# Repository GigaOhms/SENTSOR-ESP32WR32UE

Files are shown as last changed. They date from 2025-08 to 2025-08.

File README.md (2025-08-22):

# Learn KiCad Through a ESP32-micro Compact PCB Design Project

This repository is a learning resource to explore **PCB design with KiCad** through a practical project: a compact and powerful ESP32-based board.  
The reference for this project comes from [Sentsor Core ESP32-Micro](https://oshwlab.com/sentsor-project/sentsor-core-esp32-micro).

---

## Project Image

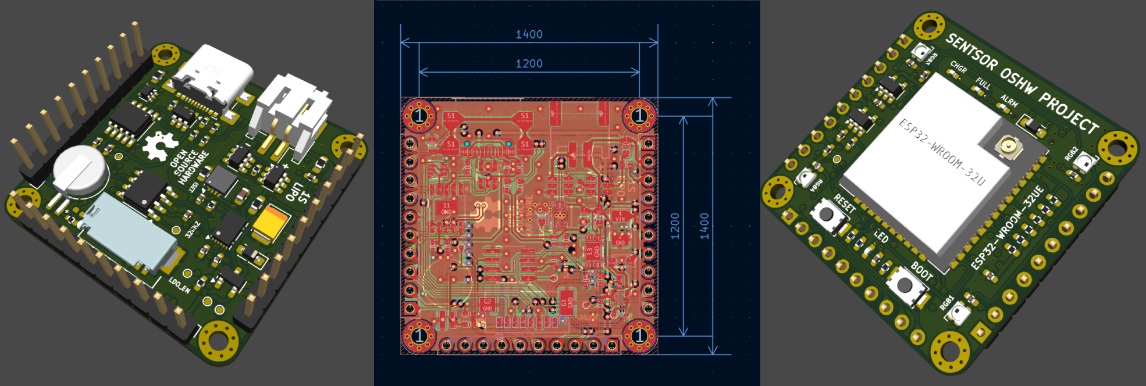
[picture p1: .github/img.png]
Project Preview


---

## Description

- **Super compact & powerful**, measured only 35.56x35.56mm (1400x1400mil) with 3x10P standard pitch 2.54mm (100mil) pinout, packing all the onboard features.  
- **ESP32-WROOM-32UE**, comes with latest ECO V3 Dual Core 32-bit LX6 microprocessor with clock up to 240MHz, ULP co-processor, 520kB SRAM, 16MB flash.  
- **802.11b/g/n WiFi Connectivity**, support mode STA/AP/STA+AP mode with external antenna using U.FL/IPEX connector allowing the board to be installed inside the enclosure without worrying transceiver signal quality.  
- **Bluetooth 4.2 Connectivity**, support classic bluetooth and Low Energy (LE) protocol.  
- **CP2104 UART to USB Bridge**, full-speed programmer & data port with auto-reset trigger using DTR and RTS line.  
- **DS3231M RTC**, extremely accurate ±5ppm RTC with alarm trigger capability and onboard MS621FE rechargeable backup battery. Connected via I2C at address 0x68.  
- **Battery Powered**, run SENTSOR board everywhere without power supply issue with 1-cell Lithium Ion/Polymer battery via JST-PH connector.  
- **CN3165 Battery Charger**, solar-powered and USB-compatible Lithium Ion/Polymer charger with on-chip adaptive charging current for wide range of input power scenario.  
- **DW01A Battery Protection**, battery usage protection against over-charge, over-discharge, over-current, and short circuit.  
- **BQ27441-G1 Battery Fuel Gauge**, accurately monitor your battery Relative State of Charge (RSOC).  
- **RT9078 & RT9013 LDO**, dual low quiescent current LDO design providing configurable +3.3V power rail up to 800mA.  
- **Super Low Power**, measured sleep mode power consumption down to XuW (XuA XV at VBAT pin, LDO2 off).  
- **Built-in LED/RGB**, single color active-low LED connected to pin IO2, and 4xSK6812 addressable RGB LED connected to pin IO4. SK6812 data out is exposed so you can chain it up with the rest of the LED circuit.  
- **MicroSD socket**, connected via SPI with slave select (SS) at pin IO5.  
- **22 pin GPIO** @3V3 level, 3xUART, 2xSPI, 2xI2C, 2xI2S, 12bit ADC, 8bit DAC, hall-effect sensing, capacitive sensing, JTAG debug, etc.  
  Please see pinout poster/schematic file for more information.  

---

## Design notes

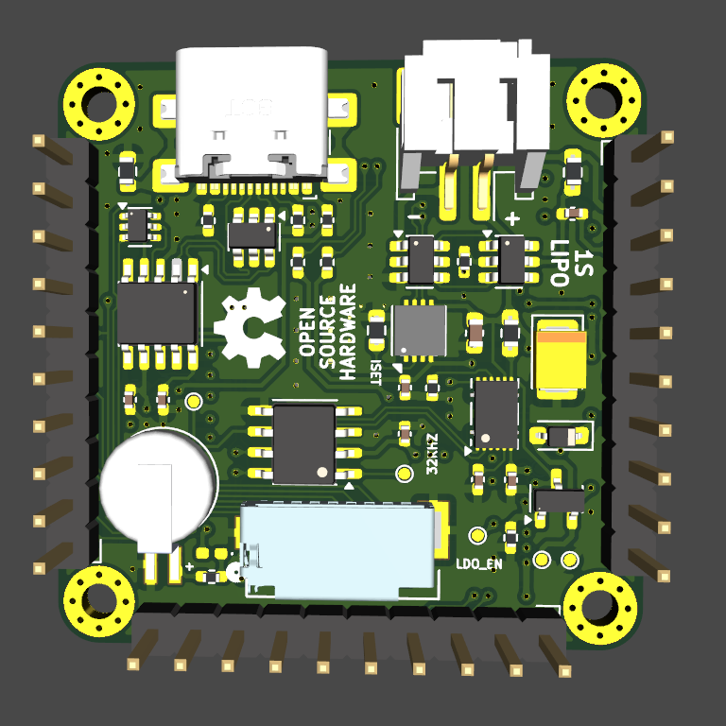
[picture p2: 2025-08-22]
.github/{3042503B-B515-44FC-A599-0AF2ED1924E2}.png

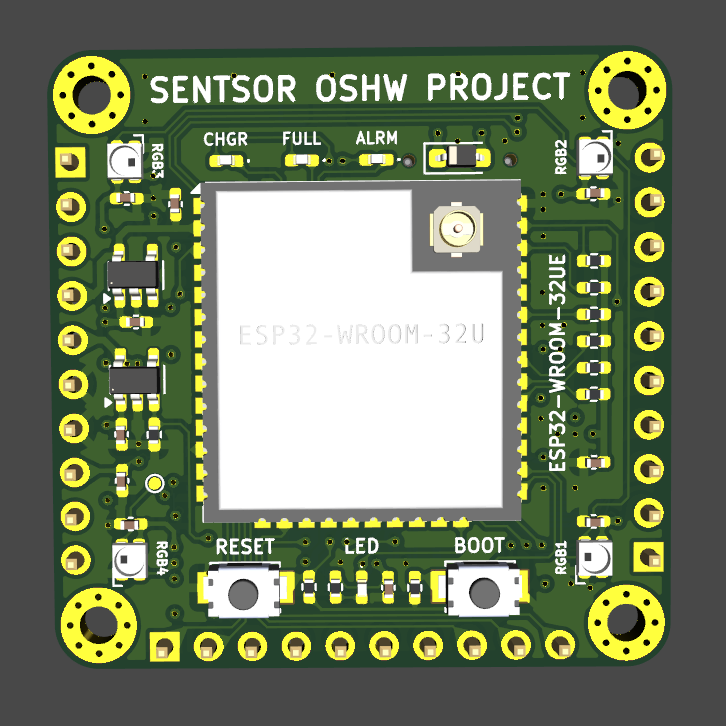
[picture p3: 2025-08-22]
.github/{C277C686-3AE4-48C9-9130-4F181D2F0E78}.png

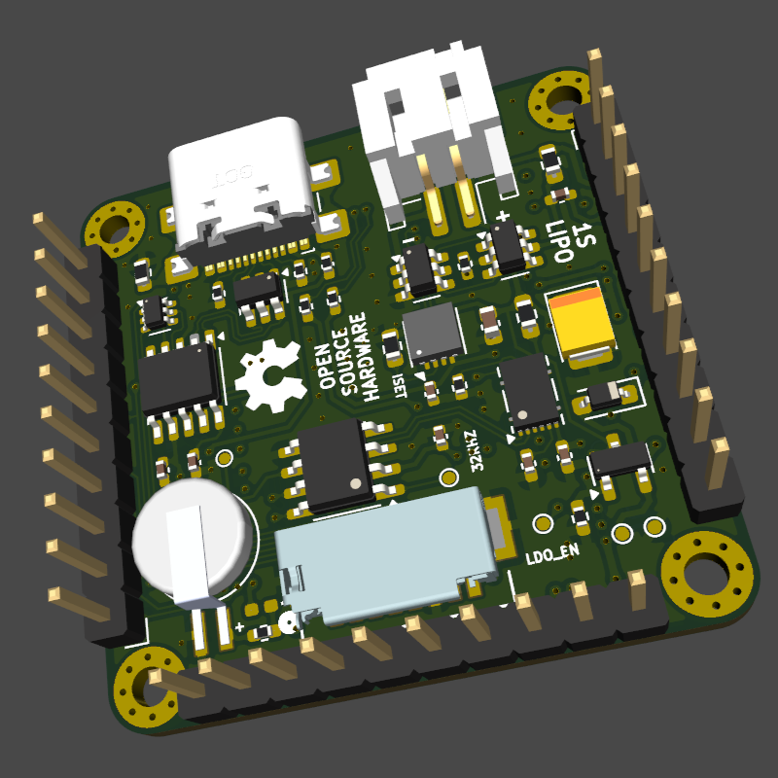
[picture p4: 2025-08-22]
.github/{8042447E-E397-4C2C-84E7-ECF5C29D7B32}.png

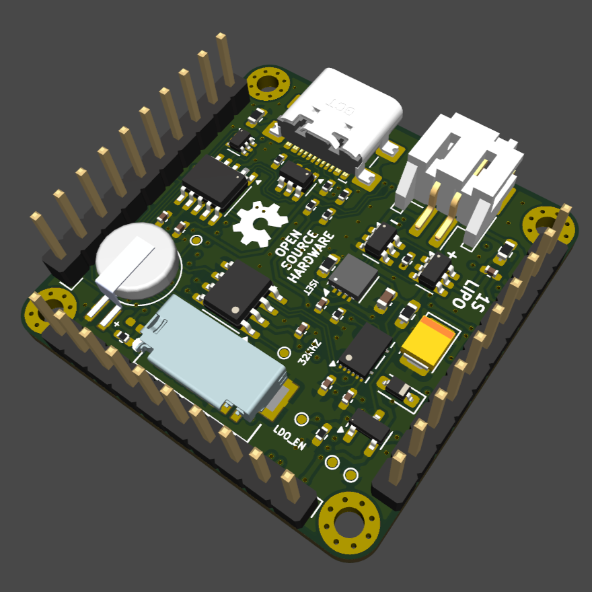
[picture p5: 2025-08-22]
.github/{378869CB-FA2F-42F7-B0C2-98885EA41B93}.png

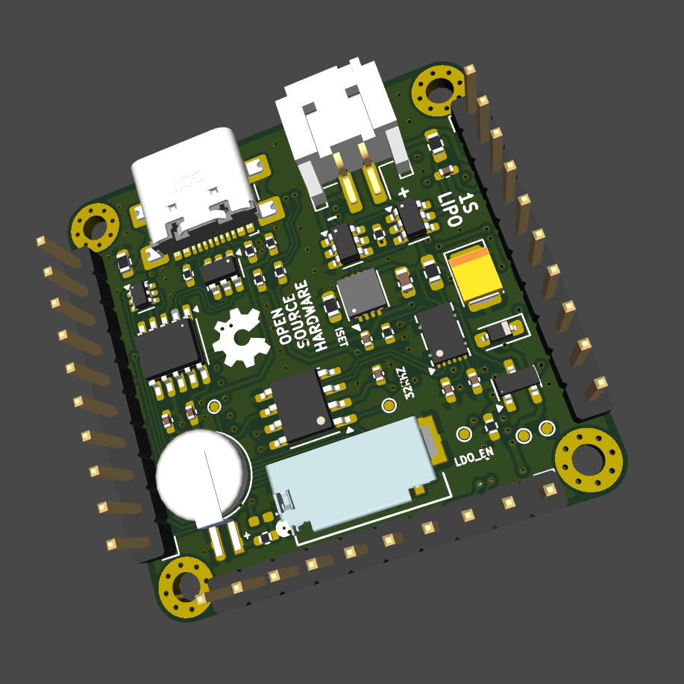
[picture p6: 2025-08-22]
.github/{2D30E0E1-55B5-4085-9390-B09677AA93EF}.png

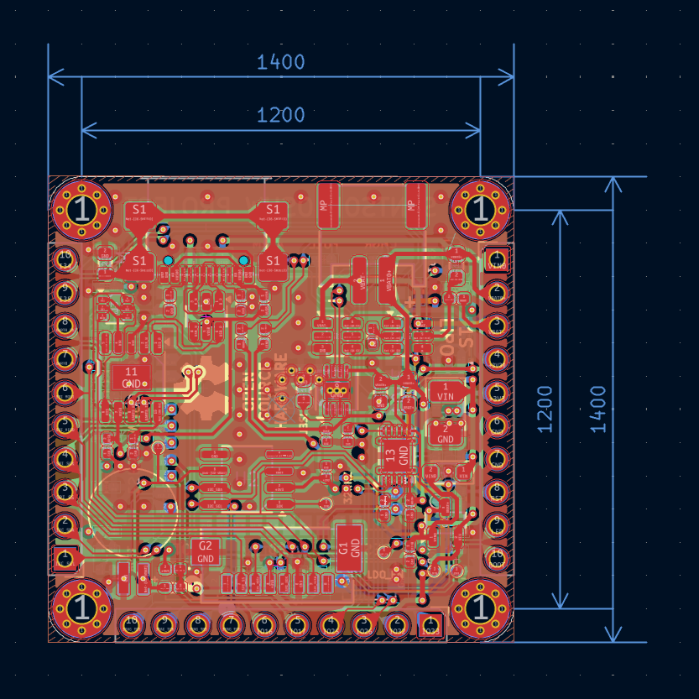
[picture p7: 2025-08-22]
.github/{8911B826-A0C5-4DD1-86A1-A8F6CBF12ACC}.png

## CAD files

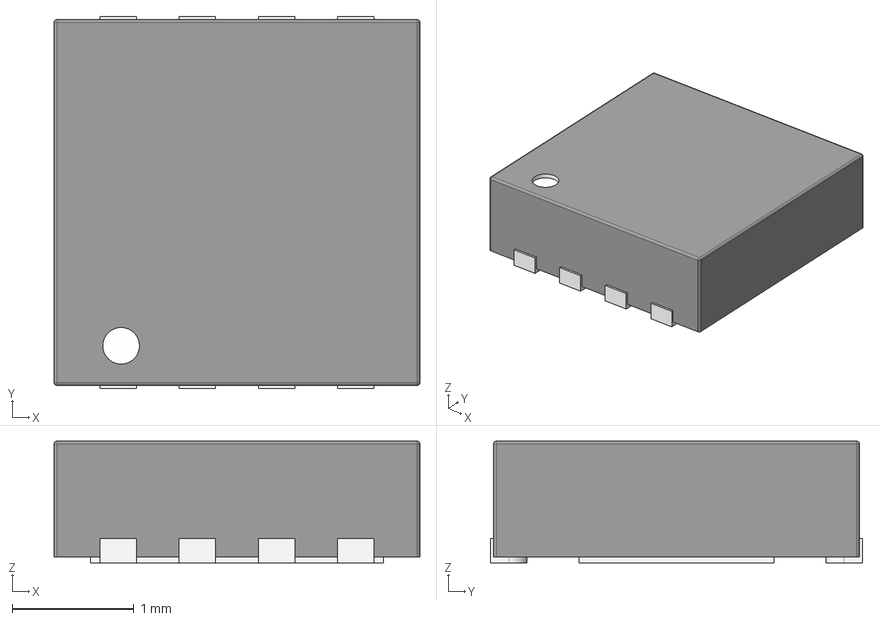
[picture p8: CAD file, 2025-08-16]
3dmodel/DFN-8 3x3.step
3.00 x 3.05 x 1.00 mm

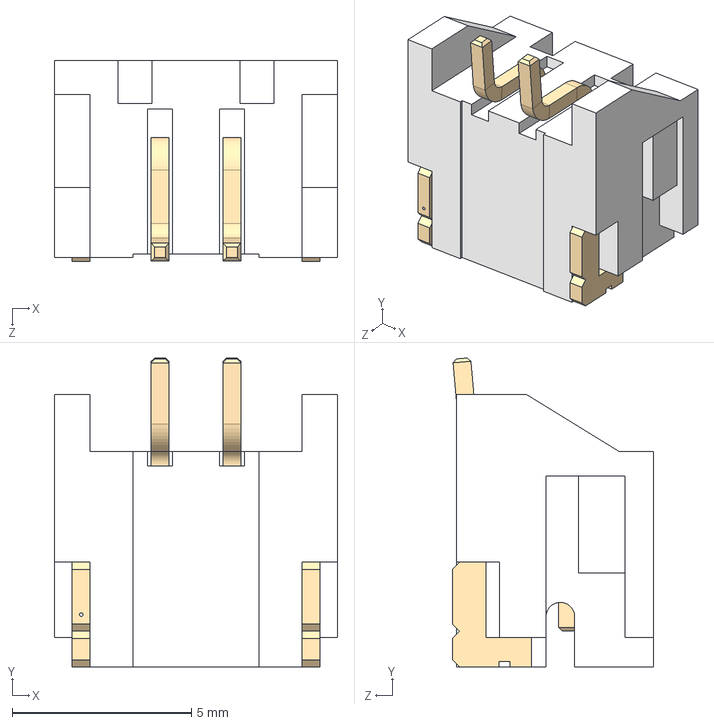
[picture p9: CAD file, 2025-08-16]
3dmodel/JST-S2B-PH-SM4-TB.STEP
7.90 x 8.61 x 5.61 mm

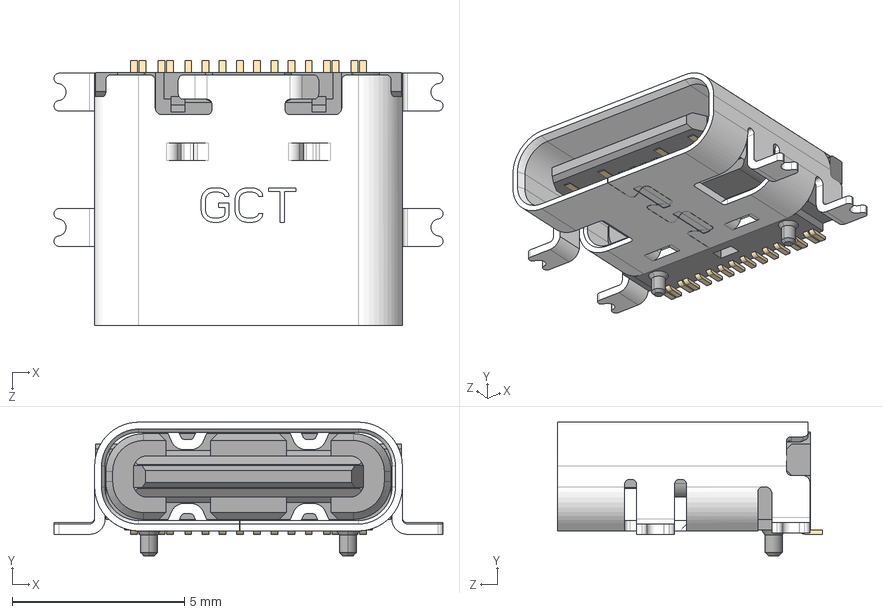
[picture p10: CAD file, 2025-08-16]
3dmodel/USB4110GFA--3DModel-STEP-269445.STEP
11.3 x 3.89 x 7.70 mm

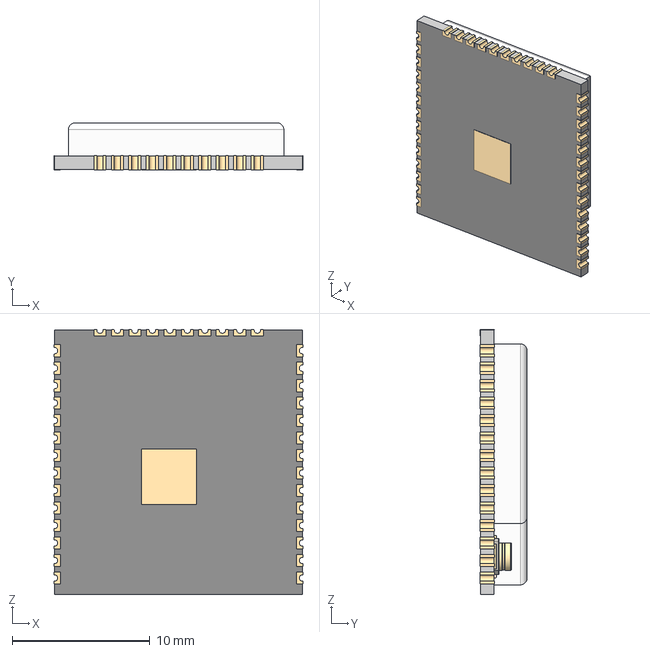
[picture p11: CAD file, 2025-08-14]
3dmodel/ESp32-WROOM-32U v3.step
18.1 x 3.44 x 19.2 mm

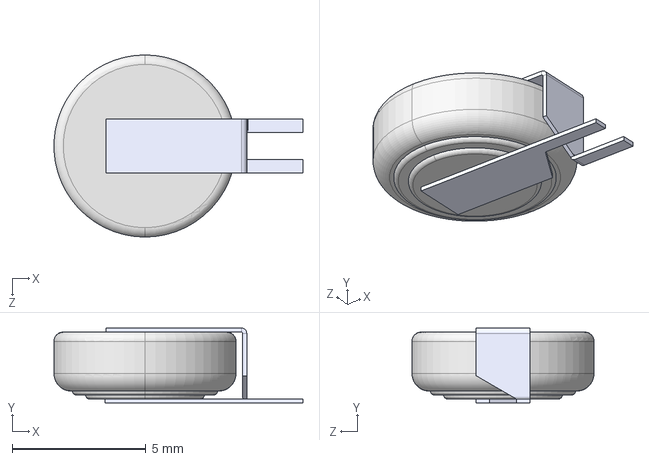
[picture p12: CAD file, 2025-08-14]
3dmodel/MS621FE.step
9.30 x 2.80 x 6.80 mm

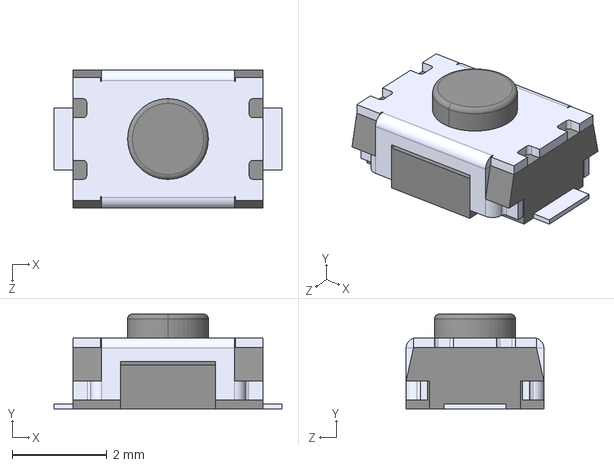
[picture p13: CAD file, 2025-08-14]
3dmodel/TS-1088-AR02016.step
4.80 x 2.00 x 2.90 mm

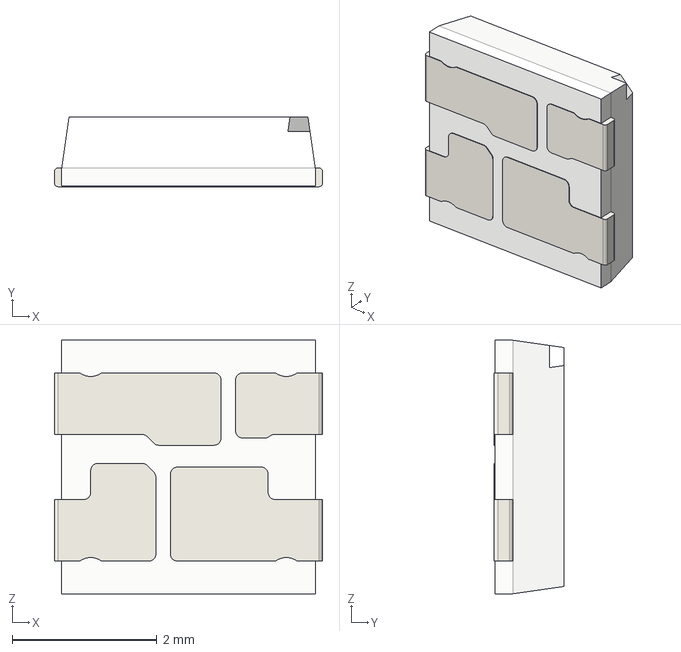
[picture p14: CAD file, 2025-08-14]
3dmodel/SMD SK6812 Super LED.step
3.70 x 0.96 x 3.50 mm

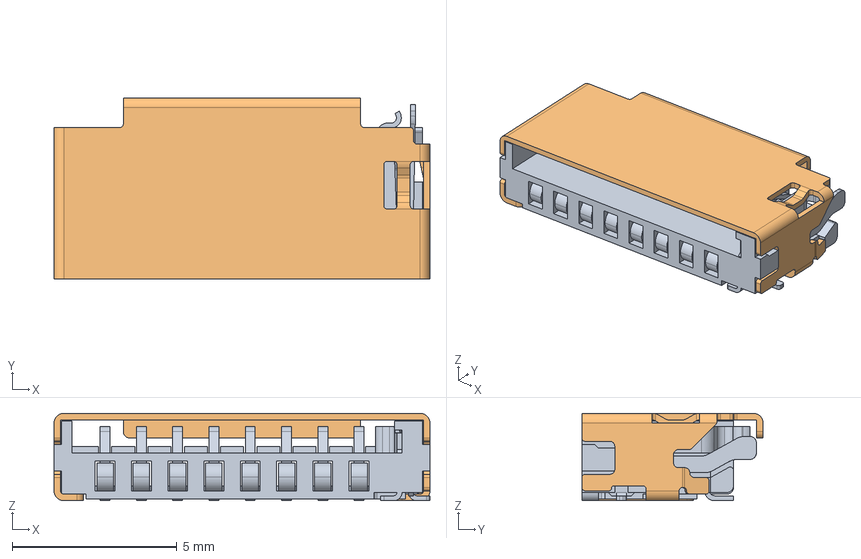
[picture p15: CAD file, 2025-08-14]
3dmodel/0473092651.stp
11.4 x 5.50 x 2.65 mm

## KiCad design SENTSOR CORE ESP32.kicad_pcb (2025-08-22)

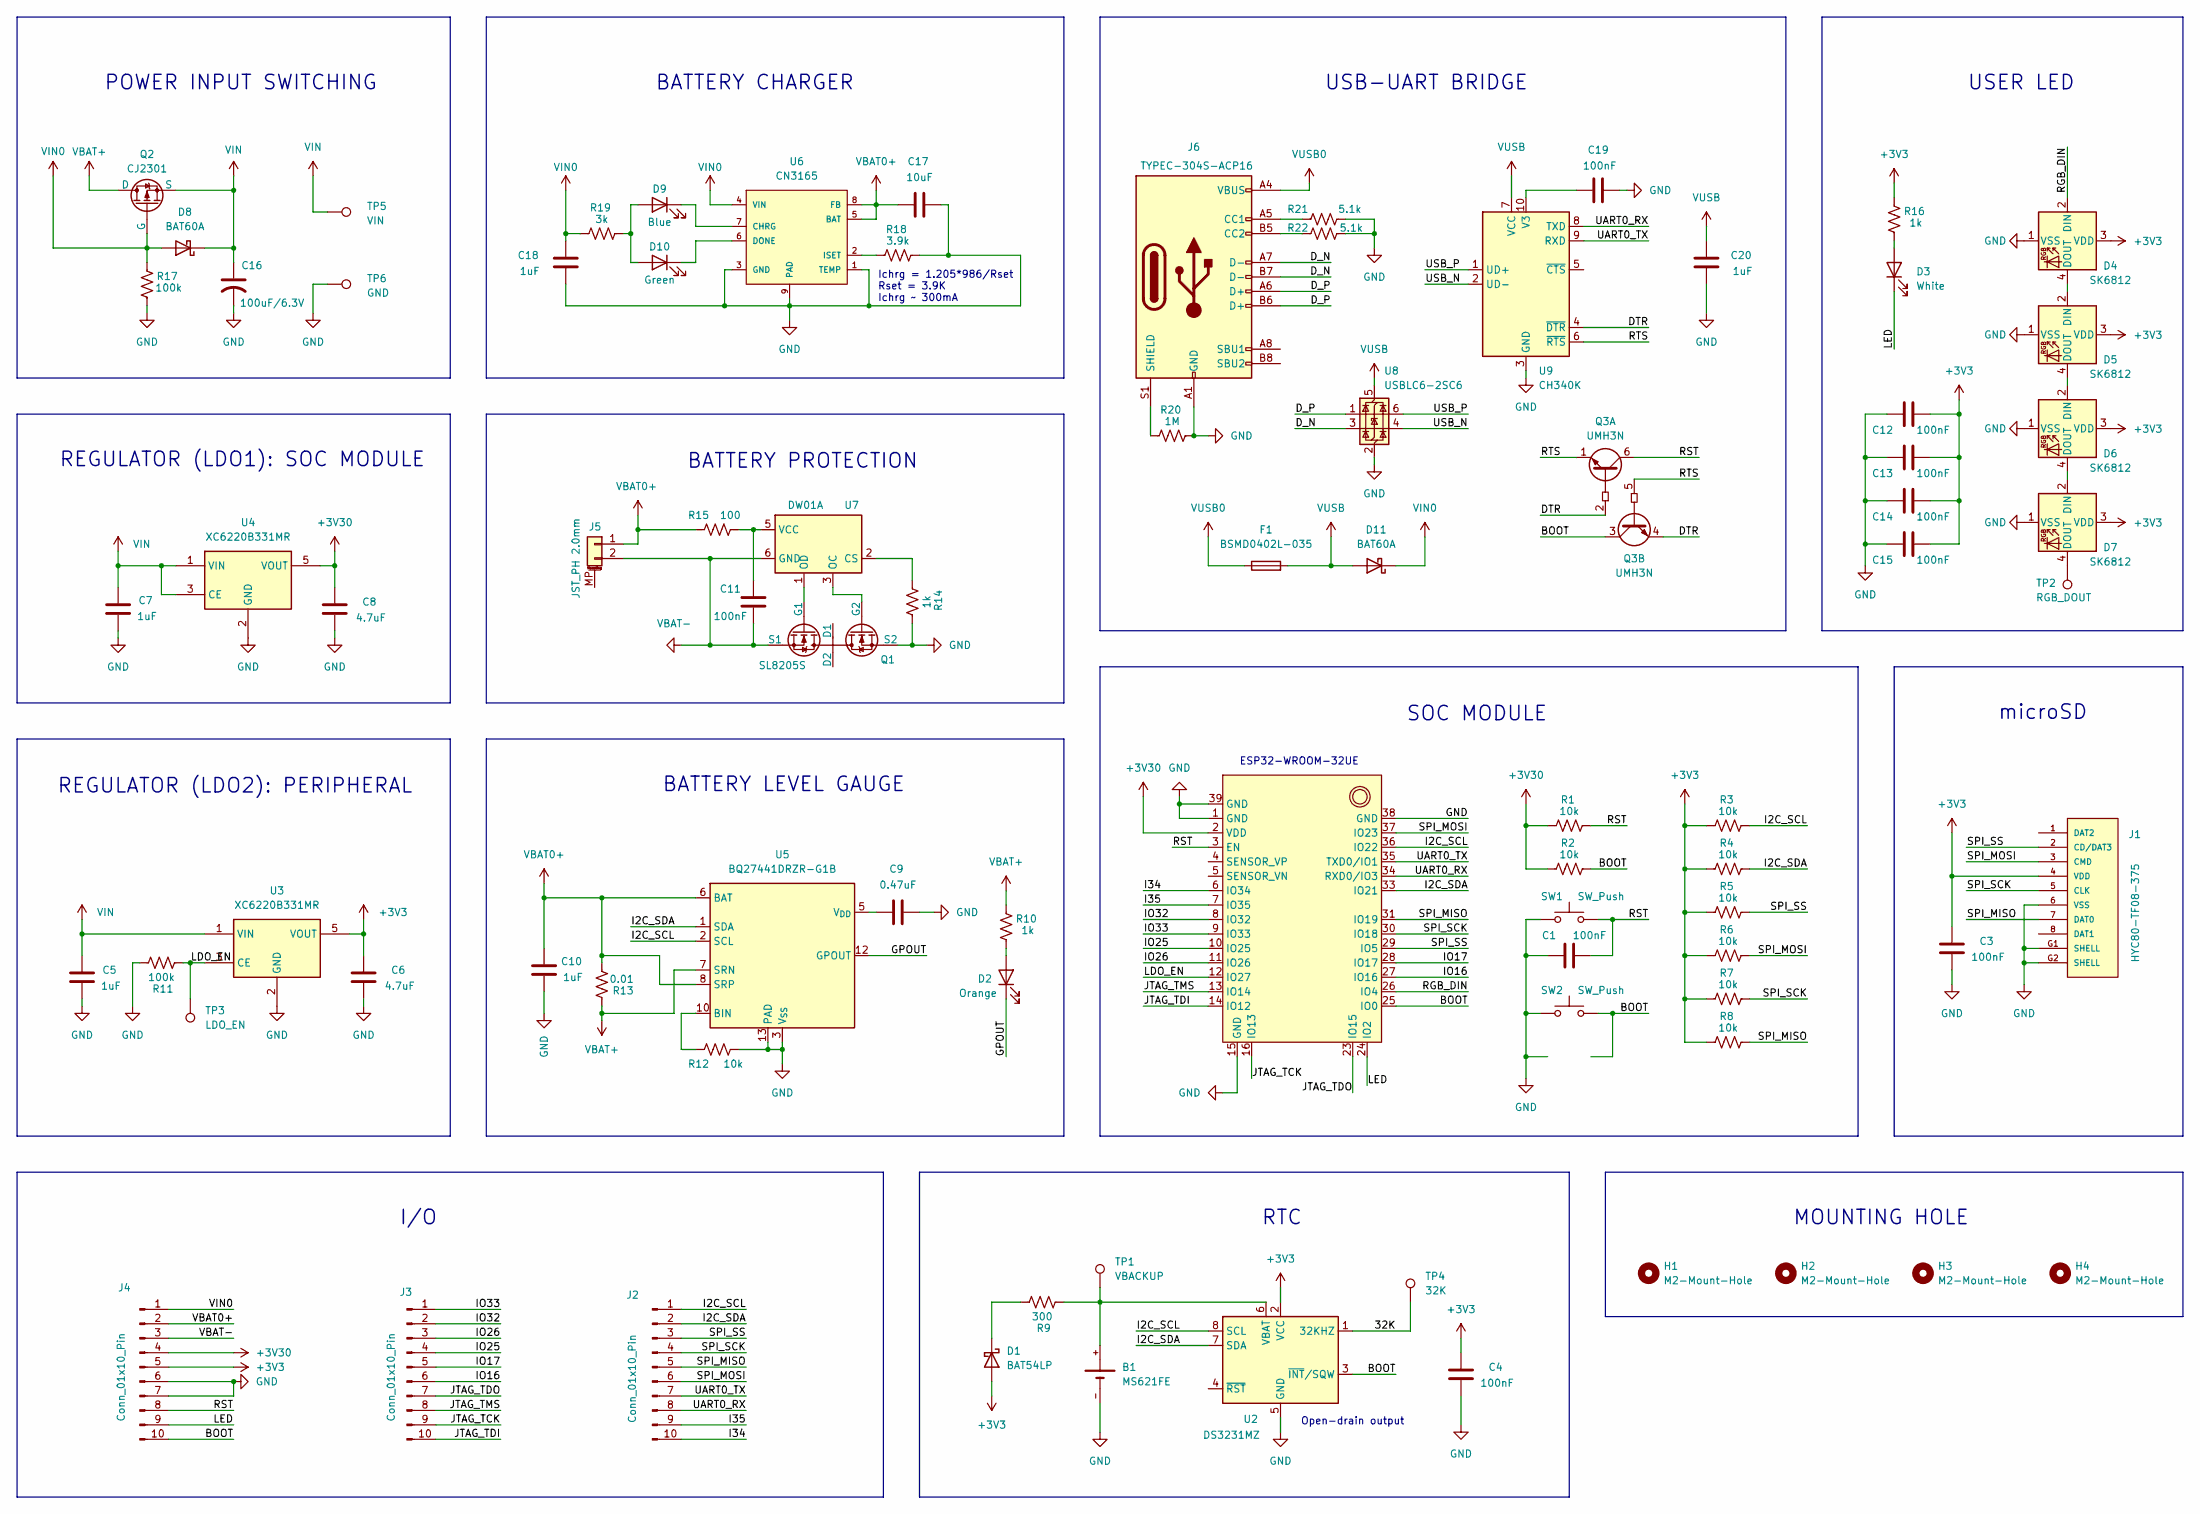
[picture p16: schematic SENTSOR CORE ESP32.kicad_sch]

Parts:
B1: MS621FE; BAT_MS621FE-SMD
C1, C3, C11, C12, C13, C14, C15, C19: 100nF; C_0402_1005Metric_Pad0.74x0.62mm_HandSolder
C4: 100nF; C_0402_1005Metric
C5, C7, C10, C20: 1uF; C_0402_1005Metric_Pad0.74x0.62mm_HandSolder
C6, C8: 4.7uF; C_0402_1005Metric_Pad0.74x0.62mm_HandSolder
C9: 0.47uF; C_0402_1005Metric_Pad0.74x0.62mm_HandSolder
C16: 100uF/6.3V; CP_EIA-3528-12_Kemet-T_HandSolder
C17: 10uF; C_0603_1608Metric
C18: 1uF; C_0402_1005Metric
D1: BAT54LP; D_0402_1005Metric_Pad0.77x0.64mm_HandSolder
D2: Orange; LED_0402_1005Metric_Pad0.77x0.64mm_HandSolder
D3: White; LED_0402_1005Metric_Pad0.77x0.64mm_HandSolder
D4, D5, D6, D7: SK6812; LED_SK6812_EC20_20x20mm
D8, D11: BAT60A; D_SOD-323_HandSoldering
D9: Blue; LED_0402_1005Metric_Pad0.77x0.64mm_HandSolder
D10: Green; LED_0402_1005Metric_Pad0.77x0.64mm_HandSolder
F1: BSMD0402L-035; Fuse_0402_1005Metric_Pad0.77x0.64mm_HandSolder
H1, H2, H3, H4: M2-Mount-Hole; MountingHole_2.2mm_M2
J1: HYC80-TF08-375; microSD_CARD_HYC80-TF08-xxx
J2, J3, J4: Conn_01x10_Pin; PinHeader_1x10_P2.54mm_Vertical
J5: JST_PH 2.0mm; JST_PH_S2B-PH-SM4-TB_1x02-1MP_P2.00mm_Horizontal
J6: TYPEC-304S-ACP16; USB_C_Receptacle_GCT_USB4110
Q1: SL8205S; SOT-23-6
Q2: CJ2301; SOT-23-3
Q3: UMH3N; SOT-363_SC-70-6
R1, R2, R3, R4, R5, R6, R7, R8: 10k; R_0402_1005Metric_Pad0.72x0.64mm_HandSolder
R9: 300; R_0402_1005Metric_Pad0.72x0.64mm_HandSolder
R10, R14, R16: 1k; R_0402_1005Metric_Pad0.72x0.64mm_HandSolder
R11, R17: 100k; R_0402_1005Metric_Pad0.72x0.64mm_HandSolder
R12: 10k; R_0402_1005Metric
R13: 0.01; R_0603_1608Metric_Pad0.98x0.95mm_HandSolder
R15: 100; R_0603_1608Metric_Pad0.98x0.95mm_HandSolder
R18: 3.9k; R_0603_1608Metric
R19: 3k; R_0402_1005Metric_Pad0.72x0.64mm_HandSolder
R20: 1M; R_0603_1608Metric
R21, R22: 5.1k; R_0402_1005Metric_Pad0.72x0.64mm_HandSolder
SW1, SW2: SW_Push; SW_2P_TS-1088-AR02016 3x4x2.5mm
TP1: VBACKUP; TestPoint_Pad_D0.7mm
TP2: RGB_DOUT; TestPoint_Pad_D0.7mm
TP3: LDO_EN; TestPoint_Pad_D0.7mm
TP4: 32K; TestPoint_Pad_D0.7mm
TP5: VIN; TestPoint_Pad_D0.7mm
TP6: GND; TestPoint_Pad_D0.7mm
U1: ESP32-WROOM-32UE
U2: DS3231MZ; SOIC-8_3.9x4.9mm_P1.27mm
U3, U4: XC6220B331MR; SOT-23-5
U5: BQ27441DRZR-G1B; Texas_S-PDSO-N12
U6: CN3165; DFN-8-1EP_3x3mm_P0.5mm_EP1.65x2.38mm_ThermalVias
U7: DW01A; SOT-23-6
U8: USBLC6-2SC6; SOT-23-6
U9: CH340K; SSOP-10-1EP_3.9x4.9mm_P1mm_EP2.1x3.3mm

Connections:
+3V3: C3.2, C4.2, C6.2, C12.2, C13.2, C14.2, C15.2, D1.2 (A), D4.3 (VDD), D5.3 (VDD), D6.3 (VDD), D7.3 (VDD), J1.4 (VDD), J4.5, R3.1, R4.1, R5.1, R6.1, R7.1, R8.1, R16.1, U2.2 (VCC), U3.5 (VOUT)
+3V30: C8.2, J4.4, R1.1, R2.1, U1.2 (VDD), U4.5 (VOUT)
/32K: TP4.1, U2.1 (32KHZ)
/BOOT: J4.10, Q3.3 (C2), R2.2, SW2.2, U1.25 (IO0), U2.3 (~INT/SQW)
/DTR: Q3.2 (B1), Q3.4 (E2), U9.4 (~DTR)
/D_N: J6.A7 (D-), J6.B7 (D-), U8.3 (I/O2)
/D_P: J6.A6 (D+), J6.B6 (D+), U8.1 (I/O1)
/GPOUT: D2.1 (K), U5.12 (GPOUT)
/I2C_SCL: J2.1, R3.2, U1.36 (IO22), U2.8 (SCL), U5.2 (SCL)
/I2C_SDA: J2.2, R4.2, U1.33 (IO21), U2.7 (SDA), U5.1 (SDA)
/I34: J2.10, U1.6 (IO34)
/I35: J2.9, U1.7 (IO35)
/IO16: J3.6, U1.27 (IO16)
/IO17: J3.5, U1.28 (IO17)
/IO25: J3.4, U1.10 (IO25)
/IO26: J3.3, U1.11 (IO26)
/IO32: J3.2, U1.8 (IO32)
/IO33: J3.1, U1.9 (IO33)
/JTAG_TCK: J3.9, U1.16 (IO13)
/JTAG_TDI: J3.10, U1.14 (IO12)
/JTAG_TDO: J3.7, U1.23 (IO15)
/JTAG_TMS: J3.8, U1.13 (IO14)
/LDO_EN: R11.1, TP3.1, U1.12 (IO27), U3.3 (CE)
/LED: D3.1 (K), J4.9, U1.24 (IO2)
/RGB_DIN: D4.2 (DIN), U1.26 (IO4)
/RST: C1.2, J4.8, Q3.6 (C1), R1.2, SW1.2, U1.3 (EN)
/RTS: Q3.1 (E1), Q3.5 (B2), U9.6 (~RTS)
/SPI_MISO: J1.7 (DAT0), J2.5, R8.2, U1.31 (IO19)
/SPI_MOSI: J1.3 (CMD), J2.6, R6.2, U1.37 (IO23)
/SPI_SCK: J1.5 (CLK), J2.4, R7.2, U1.30 (IO18)
/SPI_SS: J1.2 (CD/DAT3), J2.3, R5.2, U1.29 (IO5)
/UART0_RX: J2.8, U1.34 (RXD0/IO3), U9.8 (TXD)
/UART0_TX: J2.7, U1.35 (TXD0/IO1), U9.9 (RXD)
/USB_N: U8.4 (I/O2), U9.2 (UD-)
/USB_P: U8.6 (I/O1), U9.1 (UD+)
GND: B1.-, C1.1, C3.1, C4.1, C5.1, C6.1, C7.1, C8.1, C9.1, C10.1, C12.1, C13.1, C14.1, C15.1, C16.2, C17.1, C18.2, C19.2, C20.1, D4.1 (VSS), D5.1 (VSS), D6.1 (VSS), D7.1 (VSS), J1.6 (VSS), J1.G1 (SHELL), J1.G2 (SHELL), J4.6, J4.7, J6.A1 (GND), J6.A12 (GND), J6.B1 (GND), J6.B12 (GND), Q1.3 (S2), R11.2, R12.1, R14.2, R17.2, R18.2, R20.2, R21.2, R22.2, SW1.1, SW2.1, TP6.1, U1.1 (GND), U1.15 (GND), U1.38 (GND), U1.39 (GND), U2.5 (GND), U3.2 (GND), U4.2 (GND), U5.3 (V_{SS}), U5.13 (PAD), U6.1 (TEMP), U6.3 (GND), U6.9 (PAD), U8.2 (GND), U9.3 (GND), U9.11 (GND)
unnamed: D1.1 (K), R9.2
unnamed: D2.2 (A), R10.2
unnamed: D3.2 (A), R16.2
unnamed: D4.4 (DOUT), D5.2 (DIN)
unnamed: D5.4 (DOUT), D6.2 (DIN)
unnamed: D6.4 (DOUT), D7.2 (DIN)
unnamed: D7.4 (DOUT), TP2.1
unnamed: D9.1 (K), U6.7 (CHRG)
unnamed: D9.2 (A), D10.2 (A), R19.2
unnamed: D10.1 (K), U6.6 (DONE)
unnamed: J6.A5 (CC1), R21.1
unnamed: J6.B5 (CC2), R22.1
unnamed: J6.S1 (SHIELD), R20.1
unnamed: Q1.6 (G1), U7.1 (OD)
unnamed: Q1.4 (G2), U7.3 (OC)
unnamed: B1.+, R9.1, TP1.1, U2.6 (VBAT)
unnamed: R12.2, U5.10 (BIN)
unnamed: C9.2, U5.5 (V_{DD})
unnamed: R18.1, U6.2 (ISET)
unnamed: R14.1, U7.2 (CS)
unnamed: C11.2, R15.2, U7.5 (VCC)
unnamed: C19.1, U9.10 (V3)
VBAT0+: C10.2, C17.2, J4.2, J5.1, R13.1, R15.1, U5.6 (BAT), U5.8 (SRP), U6.5 (BAT), U6.8 (FB)
VBAT+: Q2.3 (D), R10.1, R13.2, U5.7 (SRN)
VBAT-: C11.1, J4.3, J5.2, Q1.1 (S1), U7.6 (GND)
VIN: C5.2, C7.2, C16.1, D8.1 (K), Q2.2 (S), TP5.1, U3.1 (VIN), U4.1 (VIN), U4.3 (CE)
VIN0: C18.1, D8.2 (A), D11.1 (K), J4.1, Q2.1 (G), R17.1, R19.1, U6.4 (VIN)
VUSB: C20.2, D11.2 (A), F1.2, U8.5 (VBUS), U9.7 (VCC)
VUSB0: F1.1, J6.A4 (VBUS), J6.A9 (VBUS), J6.B4 (VBUS), J6.B9 (VBUS)

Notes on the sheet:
RTC
Open-drain output
ESP32-WROOM-32UE
SOC MODULE
MOUNTING HOLE
BATTERY LEVEL GAUGE
USER LED
REGULATOR (LDO2): PERIPHERAL
microSD
USB-UART BRIDGE
I/O
BATTERY PROTECTION
Ichrg = 1.205*986/Rset Rset = 3.9K Ichrg ~ 300mA
POWER INPUT SWITCHING
REGULATOR (LDO1): SOC MODULE
BATTERY CHARGER

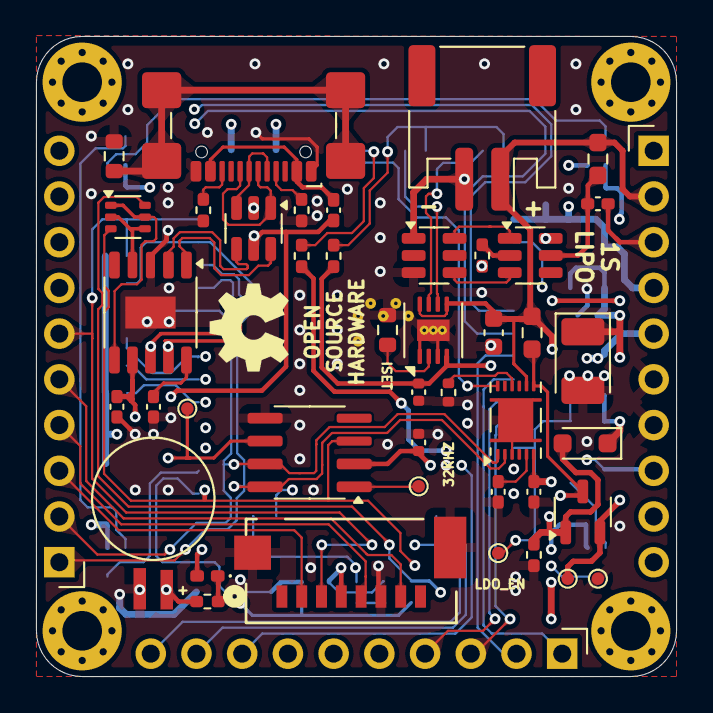
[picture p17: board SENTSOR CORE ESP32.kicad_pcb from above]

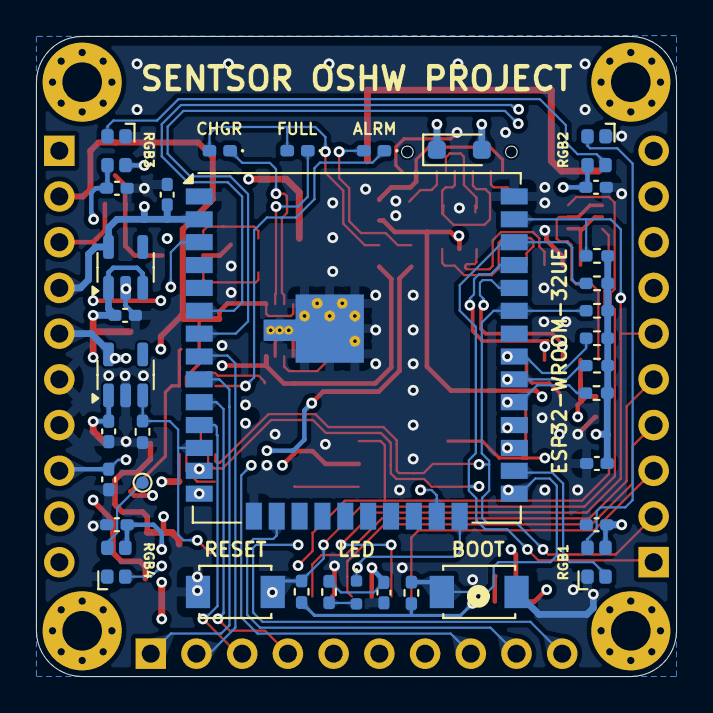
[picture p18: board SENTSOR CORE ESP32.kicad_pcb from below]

Board: 4 copper layers, 35.6 x 35.6 mm, 84 parts (35 on the bottom side), 65 nets.

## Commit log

2025-08-14 first done SCH
    [0473092651.stp, ESp32-WROOM-32U v3.step, MS621FE.step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]
2025-08-16 add board cut line
    [SENTSOR CORE ESP32.kicad_pcb, USB4110GFA--3DModel-STEP-269445.STEP]
2025-08-17 add board layout
    [SENTSOR CORE ESP32.kicad_pcb, SENTSOR CORE ESP32.kicad_sch]
2025-08-21 add board layout 85%
    [SENTSOR CORE ESP32.kicad_pcb, SENTSOR CORE ESP32.kicad_sch]
2025-08-21 add board layout 90%
    [SENTSOR CORE ESP32.kicad_pcb]
2025-08-22 add board layout 100% first
    [SENTSOR CORE ESP32.kicad_pcb]
2025-08-22 add readme
    [SENTSOR CORE ESP32.kicad_pcb]
